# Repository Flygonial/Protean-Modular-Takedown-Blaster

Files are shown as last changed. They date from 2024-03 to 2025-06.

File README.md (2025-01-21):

# Protean-Modular-Takedown-Blaster
[Build Guide](https://docs.google.com/document/d/1SjuVk3uXozs6i6hTZdHvlisbsA4GDgP2TK7CpNlB9z8/edit?usp=sharing)

[Bill of Materials](https://docs.google.com/spreadsheets/d/13hRXt3heqGb1y_bZ2tTb5aNpCZdthIEWk4YZkCei3jQ/edit?usp=sharing)

[FAQ](https://docs.google.com/document/d/1G_vJBDIBbMLpgBB6LufqcZHc96QY-UkM5tN8APzyfT4/edit?usp=sharing)

[Open Beta Fileset](https://drive.google.com/drive/folders/14amASFof2dJ1SP2ZICcWQEFaAztCsq6B?usp=sharing) (not all components complete, currently deprecated)

Buy [hardware](https://silverfoxindustries.shop/collections/hardware/products/protean-by-flygonial-beta-hardware-kit) or [printed parts](https://silverfoxindustries.shop/collections/blasters/products/protean-by-flygonial) at SilverFoxIndustries

A spiritual successor to the Gryphon, though not a replacement. Leaning further to the direction of modularity, Protean is a highly-configurable, conventional-layout mag-fed flywheel blaster. 7 takedown pins are all that stands between you and being capable of swapping flywheel cages, magwells, stocks, and pusher mechanisms with no additional tools. Not only does this make adjusting the blaster for different game velocity caps trivial, it also makes it possible to swap configurations even between rounds of an event, and in some cases replace broken parts. 

Currently supported configurations include:

* Single-stage flywheel cages between 39.5 and 43.5mm
* Dual-stage flywheel cages between 39.5 and 43.5mm
* Talon magwell
* 14.5mm or 14.0mm bore insert
* Straight PCAR or BCAR (angles from 12.5 down to 4 degrees available) bore insert
* 4-to-1 geared pusher mechanism
* Thumbscrew-secured and notch-locking rod stocks
* Fixed battery stock in short and extended lengths.
* Buffer tube battery stock (refer to [the Gryphon](https://github.com/Flygonial/The-Gryphon-Foam-Dart-Blaster) for stock files)

Configurations in the open beta include:

* Solenoid pusher mechanism (Out of Darts Neutron)
* Flatbar Battery Stock with squeeze-to-collapse mech
* Bolt-secured flywheel cages (require additional M3 Nut, M3x35 bolt, 2 M3 heatset inserts, and additional M3x10 bolts).

Future features planned include:

* Full-length receiver
* Hurricane and microwheel geometry support
* Microcontroller-driven select-fire and single-trigger control with plug & play code

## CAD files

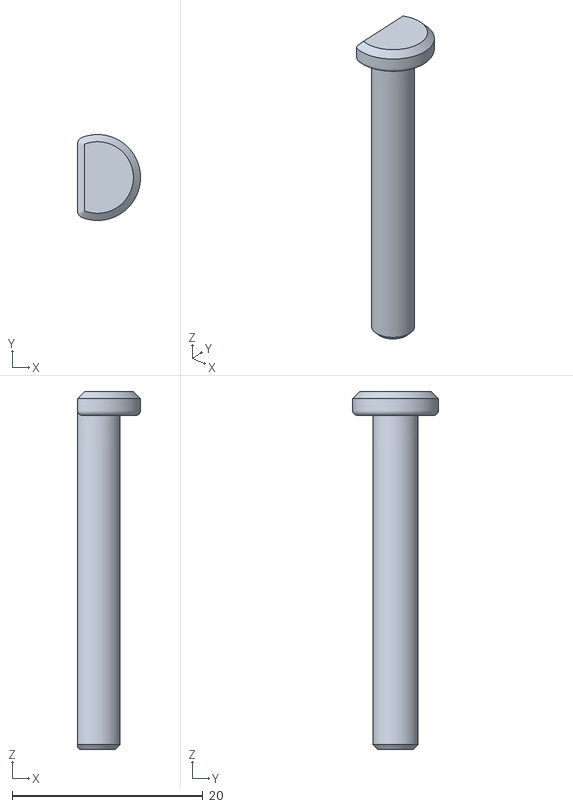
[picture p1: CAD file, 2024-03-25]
Accessories/316x1in Pin.stl
6.61 x 9.00 x 37.5

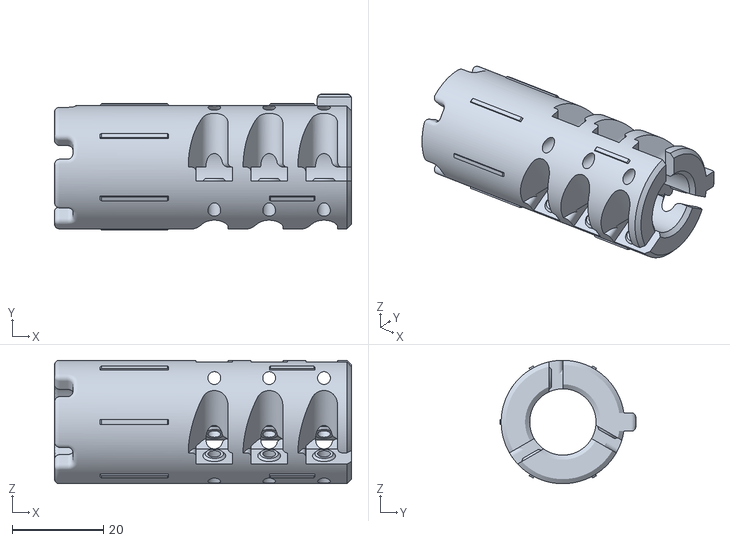
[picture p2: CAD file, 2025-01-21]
Accessories/Barrel Attachments/Inline0DegCW BCAR T.stl
65.0 x 29.7 x 27.0

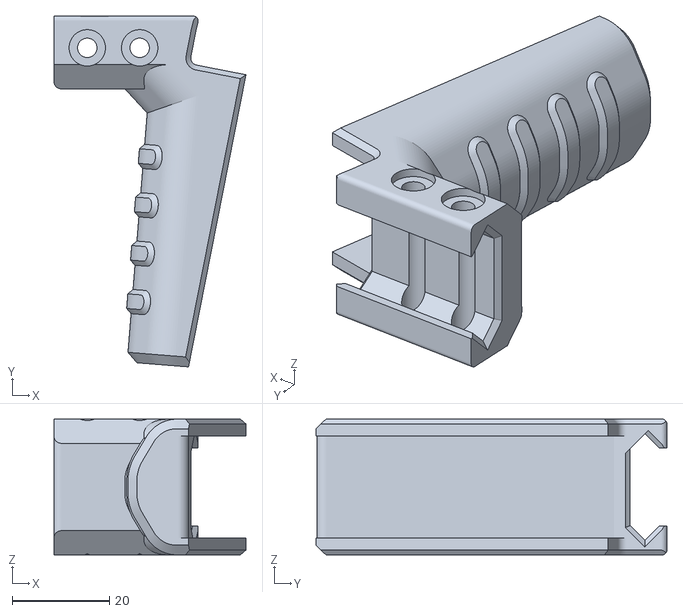
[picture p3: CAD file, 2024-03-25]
Accessories/Grips/Magwell Grip.stl
39.6 x 72.3 x 28.0

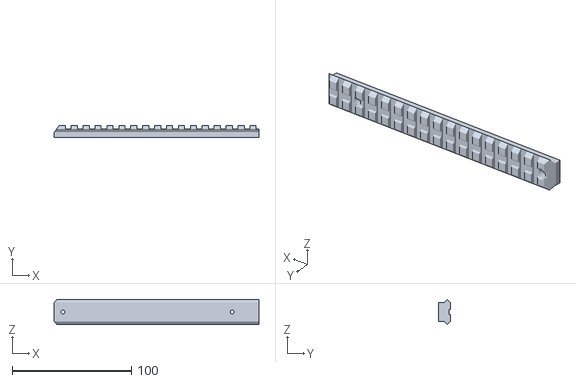
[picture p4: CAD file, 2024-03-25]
Accessories/Picatinny/Receiver Cover Picatinny (Talon).stl
172.0 x 10.0 x 21.2

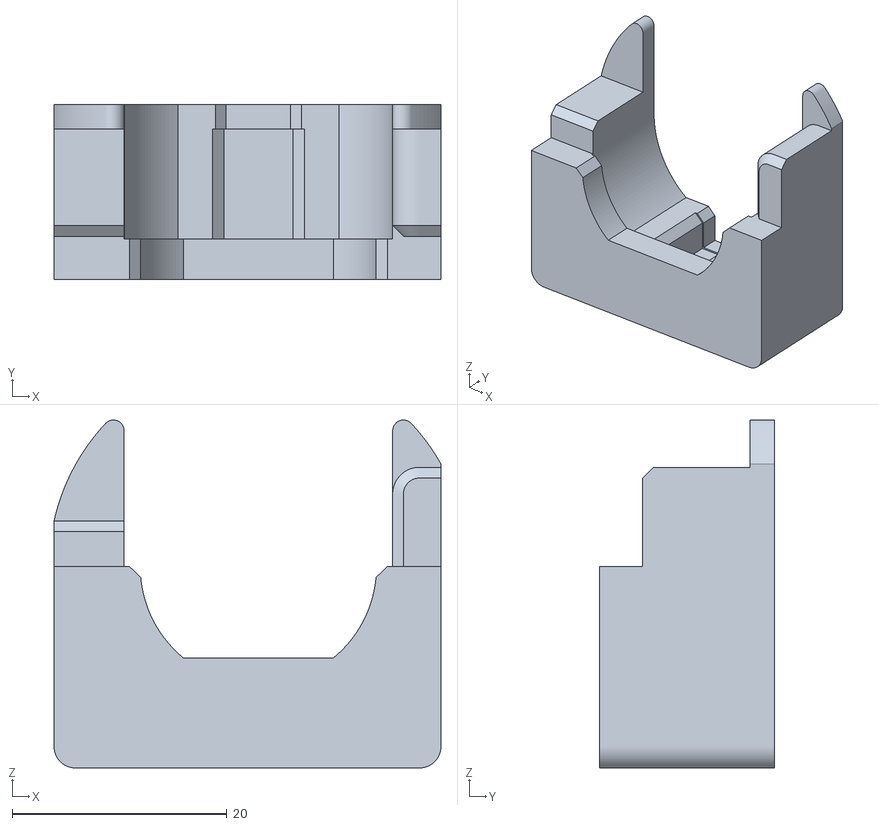
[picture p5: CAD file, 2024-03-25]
Accessories/Wheel Installation Guides/Wheel Installation Guide BB.stl
36.0 x 16.2 x 32.4

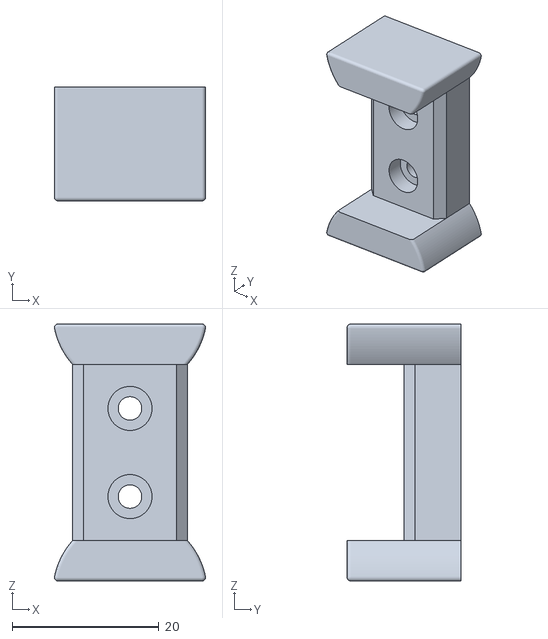
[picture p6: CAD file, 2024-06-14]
Flywheel Cage/1S FWC/1S Blend Piece.stl
20.6 x 15.5 x 35.0

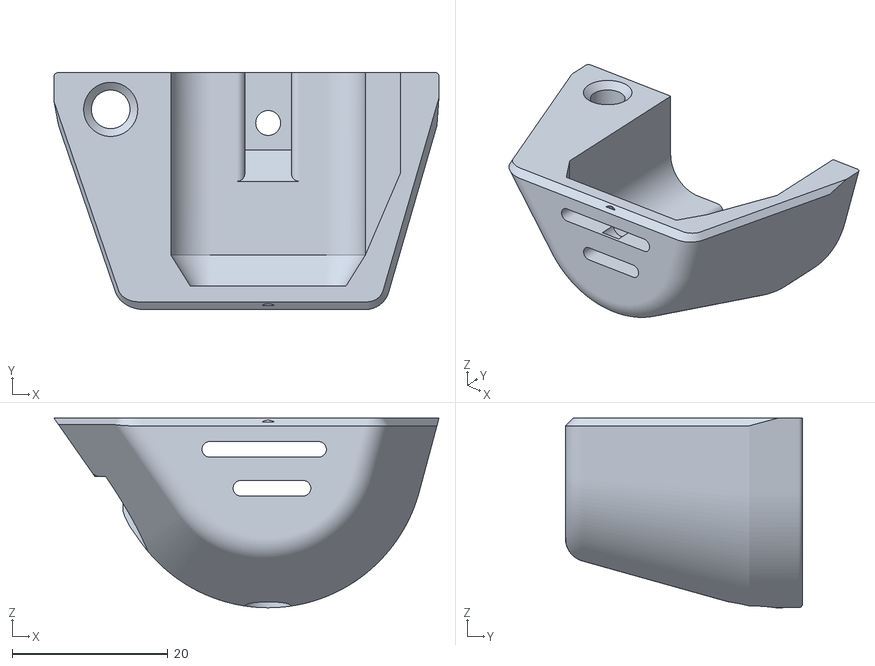
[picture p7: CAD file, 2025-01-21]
Flywheel Cage/1S FWC/Imperial/1S Motor Cover 316 (R).stl
49.5 x 30.5 x 24.4

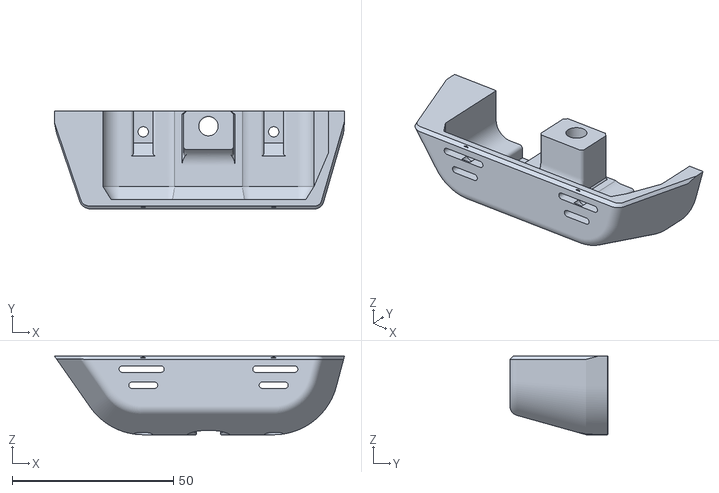
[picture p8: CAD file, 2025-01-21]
Flywheel Cage/2S FWC/Imperial/2S Motor Cover 316 (R).stl
90.0 x 30.5 x 24.4

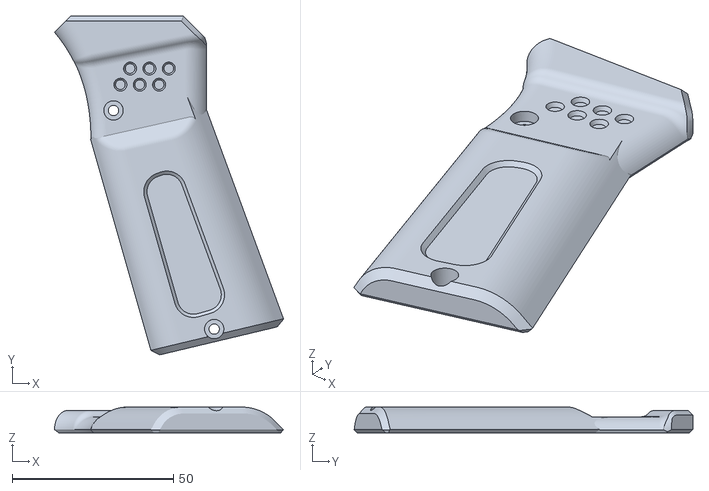
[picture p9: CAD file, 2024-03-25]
Pusher Group/Geared Semi-Auto/Left Panel (S).stl
71.0 x 105.0 x 8.00

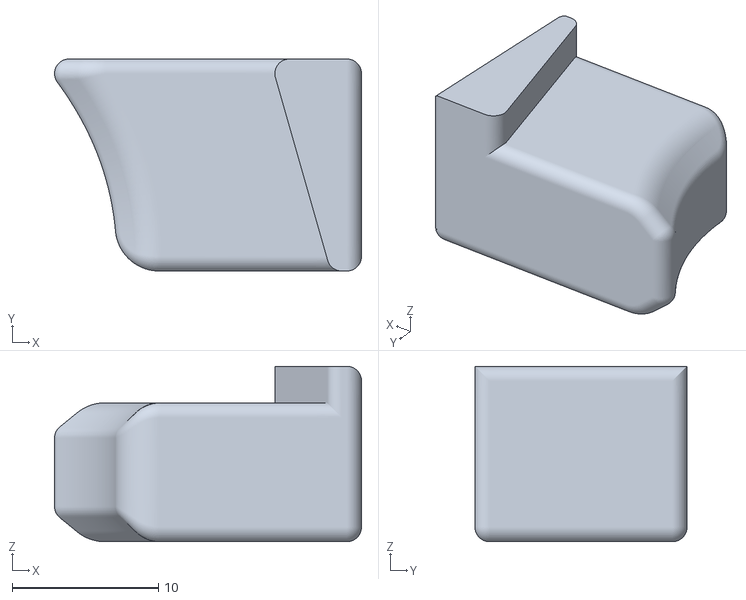
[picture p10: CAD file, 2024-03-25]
Pusher Group/Rev Trigger.stl
21.0 x 14.5 x 12.0

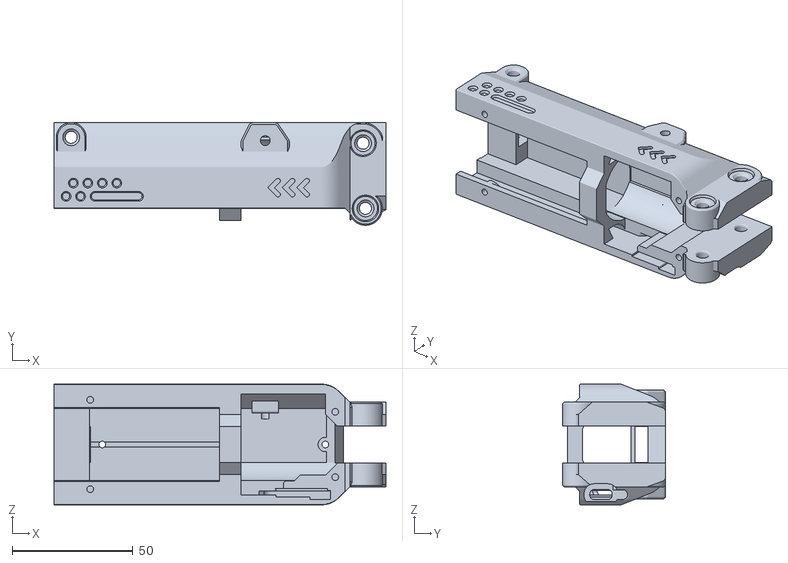
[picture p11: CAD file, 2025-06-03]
Pusher Group/Solenoid Pusher/Neutron Pusher Cover 316 (Worker).stl
137.5 x 42.5 x 50.0

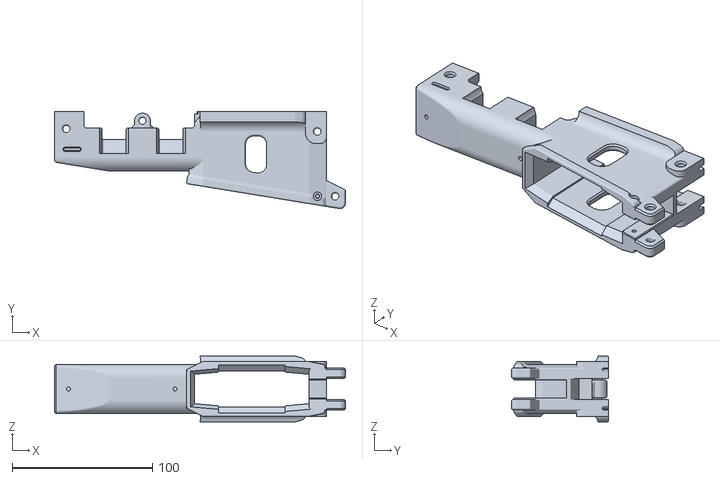
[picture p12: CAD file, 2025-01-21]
Receiver/Receiver (Full-Length)/FL Magwell.stl
207.5 x 69.3 x 47.0

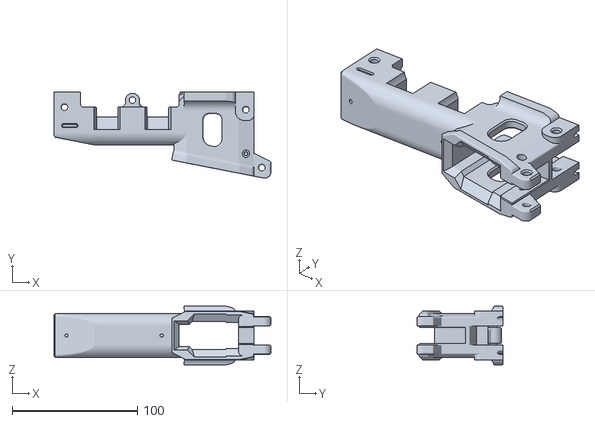
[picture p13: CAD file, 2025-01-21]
Receiver/Receiver (Half-Length)/Magwell (Talon).stl
173.5 x 69.1 x 47.0

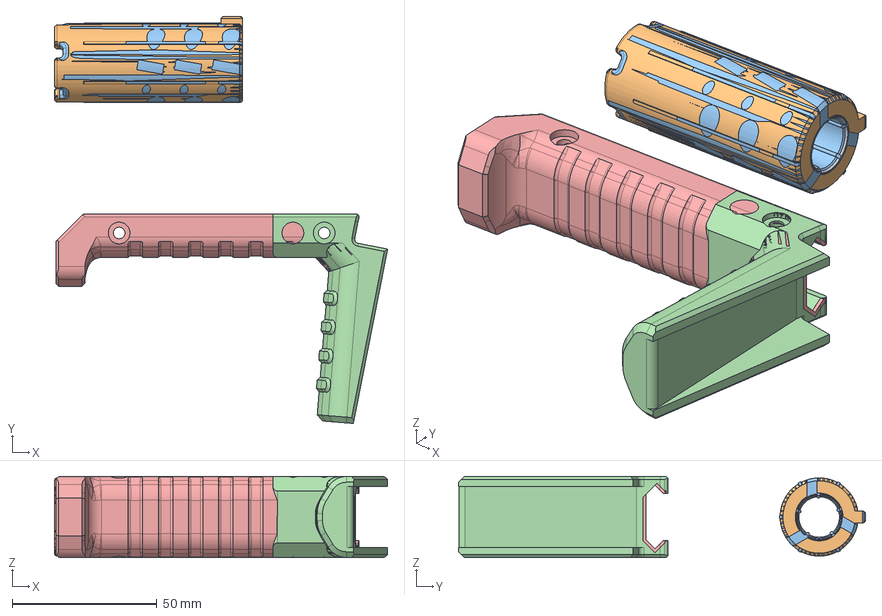
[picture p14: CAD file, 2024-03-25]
Source/Accessories STEP.step
115.1 x 140.5 x 28.0 mm
14.5 Bore
BCAR
PCAR
Foregrips

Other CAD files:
Flywheel Cage/1S FWC/Metric/1S Motor Cover (R).stl
Flywheel Cage/2S FWC/Metric/2S Motor Cover (R).stl
Stock/Buffer Tube/Buffer Top Mount.stl
Stock/Rod Stock/Notched/Buttplate (Notched).stl
Accessories/316x2in Pin.stl
Accessories/BCAR Legacy/Inline10DegCW BCAR T.stl
Accessories/BCAR Legacy/Inline10DegCW BCAR.stl
Accessories/BCAR Legacy/Inline12.5DegCW BCAR T.stl
Accessories/BCAR Legacy/Inline12.5DegCW BCAR.stl
Accessories/BCAR Legacy/Inline4DegCW BCAR T.stl
Accessories/BCAR Legacy/Inline4DegCW BCAR.stl
Accessories/BCAR Legacy/Inline5DegCW BCAR T.stl
Accessories/BCAR Legacy/Inline5DegCW BCAR.stl
Accessories/BCAR Legacy/Inline6DegCW BCAR T.stl
Accessories/BCAR Legacy/Inline6DegCW BCAR.stl
Accessories/BCAR Legacy/Inline7.5DegCW BCAR T.stl
Accessories/BCAR Legacy/Inline7.5DegCW BCAR.stl
Accessories/BCAR Legacy/Inline7DegCW BCAR T.stl
Accessories/BCAR Legacy/Inline7DegCW BCAR.stl
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

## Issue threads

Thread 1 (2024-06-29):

The fitment of the BCAR is not right

MireskaWillow, 2024-06-29:
I found the bearings of the BCAR scraping against the magwell and receiver and they cannot spin freely.

I checked the STEP files and I believe the geometry needs adjusting.

The inner radius of the muzzle cutout is 13.75. The outer radius of the BCAR is 13.50 leaving 0.25mm clearance.

The edge of the bearing screw hole is 2.396mm from the outer edge of the BCAR. The hole is 2.8mm.

(2.396 + 2.8/2 + 0.25) * 2 = 8.092mm

Now the flanged bearings are 8.1mm

There's no way this fits if printed accurately.

MireskaWillow, 2024-06-29:
Actually I do not know what size F683 bearing flanges are supposed to be, but the ones in your Amazon link, and the ones I bought from Shopee, are both 8.1mm.

I believe using a smaller bearing may fix the issue. I am currently searching for one.

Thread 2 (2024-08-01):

Location of auto trigger stl's?

will-o-matic, 2024-08-01:
Hey, I'm working on building the solenoid variant, but I don't see the auto grip files in the repo.  Any chance you can point me to them?

On another note, if you're looking for help with the coding side, hit me up.  I love a good hardware project.

MireskaWillow, 2024-08-01:
Long ago I found them in the beta files linked in the readme. Are they still there? I transitioned to AEBs and have not kept up with flywheel projects.

will-o-matic, 2024-08-01:
Ha right in front of my eyes.  Thank you!!

Closed 2024-08-01.

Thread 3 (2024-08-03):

Trigger Cover (A) doesn't fit on Grip Frame (A)

will-o-matic, 2024-08-03:
I printed the auto versions of the Trigger Cover and Grip Frame.  The cover lines up well with the frame, except on the top left corner, the wedge shape on the back of the trigger cover prevents it from sitting nicely against the grip frame.  As is, I can't see a way to make it fit.  I'm happy to edit the STEP files to fix it, but I want to make sure I'm not missing something before I do.  How are these supposed to go together?

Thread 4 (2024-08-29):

Bcar too tight

spaceffox, 2024-08-29:
The bearings are too tight on the dart causing inaccuracy and whirly birding

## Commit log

2024-03-25 V1.0: Initial fileset upload
    Most of the files, save the accessories due to the web online upload limit.
    [1S 39.5mm FWC 316.stl, 1S 39.5mm FWC.stl, 1S 40mm FWC 316.stl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]
2024-03-25 V1.0: Accessories initial upload
    As these went over the online upload limit, here they are.
    [14.0 Barrel T.stl, 14.0 Barrel.stl, 14.5 Barrel T.stl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]
2024-05-02 V1.01 Update: Bulked up fixed short stock
    After finding out firsthand that the bottom buttplate mount hole was fragile, I beefed it up (5 -> 10mm) and added a chamfer and partial fillet for now. Buttplates remain reverse-compatible, but a longer bolt (M3x16, or longer if you use a printed thumbscrew) is now likely necessary).
    [Fixed Short Stock 316.stl, Fixed Short Stock.stl]
2024-06-14 V1.02 Update: Bolt Flywheel Cage
    Mounted with two M3x20 bolts in the center and one M3x30 bolt down the front (plus two heatset inserts and 1 hex nut), this is a flywheel cage option that should help dampen vibrations from your cage somewhat (a bit of an issue given the original pin mounting system seems prone to issues from vibration). It was mostly finished a while ago, but an error was made when modeling it and the cages needed to be re-exported.
    [1S 39.5mm FWC B.stl, 1S 40mm FWC B.stl, 1S 41.5mm FWC B.stl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]
2024-06-14 V1.02 Update: Minor Fixes and Bolt Magwell
    There were some minor modeling errors, also on the flywheel cage too (where the magwell design was changed, and the blend piece was not re-exported. Any fitment issues from that should be gone. Some minor chamfers on the magwell were also asymmetric (which were lost from some timeline errors). Also included the new 'bolt' magwell for the bolt-on cage variants.
    [Magwell (Talon).stl, Magwell 316 (Talon).stl, Magwell B (Talon).stl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]
2024-06-14 V1.02 Update: Bolt Magwell and minor fixes
    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
2024-06-14 V1.02 Update: No spin BCAR added
    The inline straight BCAR was tested in a preliminary test with Worker HE green tip/heavies and Roboman's new Manshee wheels. It reduced horizontal spread slightly and significantly tightened up vertical spread. Though it's arguably still too high crush, it also has been observed bleeding 2-3~ less FPS across the chrono vs. a 7.5 degree BCAR at 175-180 FPS (no muzzle device velocity).
2025-01-21 V1.1 BCAR Legacy Upload
    A reorganization into the legacy design folder
    [Inline10DegCW BCAR T.stl, Inline10DegCW BCAR.stl, Inline12.5DegCW BCAR T.stl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]
2025-01-21 V1.1 BCAR update:
    Updated the BCAR to a MF63ZZ design, accepting smaller 3x6x2.5 bearings. This should substantially reduce the deformation/crush on your darts, resulting in better consistency and less FPS loss.
    [Inline0DegCW BCAR T.stl, Inline0DegCW BCAR.stl, Inline10DegCW BCAR T.stl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]
2025-01-21 V1.1 Motor Cover Update
    Updated with Quickdraw motor support and cutouts.
    [1S Motor Cover B (L).stl, 1S Motor Cover B (R).stl]
2025-01-21 V1.1 Motor Cover updates
    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
    [1S Motor Cover 316 (L).stl, 1S Motor Cover 316 (R).stl]
2025-01-21 V1.1: Motor Cover update
    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
    [1S Motor Cover B (L).stl, 1S Motor Cover B (R).stl]
2025-01-21 V1.1 Motor cover changes
    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
    [2S Motor Cover B (L).stl, 2S Motor Cover B (R).stl]
2025-01-21 V1.1 Update: Solenoid Pusher Group
    Added on with single trigger, rev options, though no select-fire currently.
    [6-32 Pusher Endcap.stl, Grip Frame (A).stl, Grip Frame 316 (A).stl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]
2025-01-21 V1.1 Update: Receiver changes
    Minor modifications to the motor and wiring clearance.
    [Magwell (Talon).stl, Magwell 316 (Talon).stl, Magwell B (Talon).stl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]
2025-01-21 V1.1 Update: Full-length receiver variant
    Full-length, with bolt, imperial, and metric compatibility, single and two-stage.
    [FL 2S Receiver Cover 316.stl, FL 2S Receiver Cover.stl, FL Magwell 316.stl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]
2025-06-03 V1.1 Fix: Replaced Solenoid Pusher Covers
    These were wrong for a while. Finally got around to fixing it.
    [Neutron Pusher Cover (L).stl, Neutron Pusher Cover (Worker).stl, Neutron Pusher Cover 316 (L).stl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]
